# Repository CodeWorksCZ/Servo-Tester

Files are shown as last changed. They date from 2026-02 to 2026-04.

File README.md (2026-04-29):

# Servo Tester

> **Work In Progress (WIP):** This project is under active development.  
> Features, wiring, and behavior may change between commits.

RC servo tester for Arduino Pro Mini (ATmega328P, 16 MHz) with OLED UI, settings in EEPROM, and 3-channel current monitoring via INA3221.

User manual: `MANUAL.md`

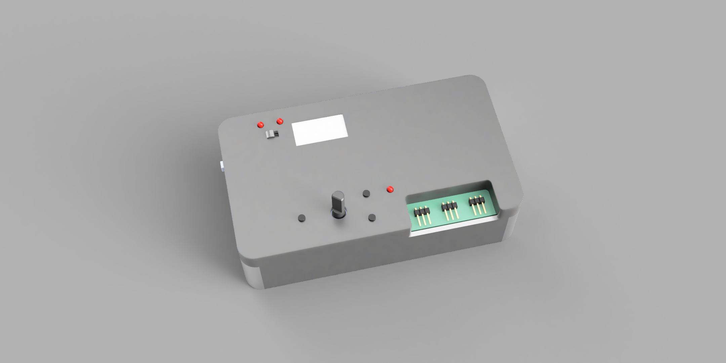
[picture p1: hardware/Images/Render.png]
Servo Tester Render


## Features

- Servo control modes: `POT`, `CENTER`, `SWEEP`
- OLED screens: `STATUS`, `GAUGE`, `CURRENT`, `VBUS`, `PEAK`
- SWEEP cycle counter shown only in SWEEP mode
- Settings menu with EEPROM persistence
- INA3221 current measurement on 3 channels
- INA3221 bus voltage and droop (`dV`) view per channel
- INA3221 per-channel warning/critical current alerts (`WR`/`CR`)
- Optional alert LED output when any channel is in `WR` or `CR`
- Optional STD/HV mode indicator LEDs
- LED startup self-test
- Automatic unit display (`mA` / `A`) on current screens
- Servo rail mode detection (`STD` / `HV`) from ADC voltage sensing on `A1`
- Compile-time UI language selection through `include/config.h` and `include/lang.h`
- Minimal serial debug line for INA3221 communication check at boot

## Controls

- `SELECT` short press: switch LCD screen (`STATUS -> GAUGE -> CURRENT -> VBUS -> PEAK`)
- `SELECT` long press: enter settings menu
- `UP` / `DOWN` in status mode: change control mode (`POT`, `CENTER`, `SWEEP`)
- `UP` / `DOWN` in menu: navigate items or change value
- `SELECT` in menu: confirm

## Settings Menu

- `Min pulse` (us)
- `Max pulse` (us)
- `Reverse`
- `Sweep cycle` (0.5-10.0 s, default 3.0 s)
- `Burn cycles` (`0` = infinite SWEEP, otherwise stop after selected cycle count)
- `Save & exit`
- `Cancel`

## Pin Mapping (Default)

| Arduino Pin | Config Name | Function |
| --- | --- | --- |
| `D2` | `BTN_UP_PIN` | UP button |
| `D3` | `BTN_DOWN_PIN` | DOWN button |
| `D4` | `ALERT_LED_PIN` | Optional INA3221 warning/critical alert LED |
| `D5` | `BTN_SELECT_PIN` | SELECT button |
| `D6` | `SERVO_PIN` | Servo signal output |
| `D7` | `STD_MODE_LED_PIN` | STD servo rail indicator LED |
| `D8` | `HV_MODE_LED_PIN` | HV servo rail indicator LED |
| `D9` | `OLED_CLK` | OLED clock (`CLK` / `D0`) |
| `D10` | `OLED_MOSI` | OLED data (`MOSI` / `DIN` / `D1`) |
| `D11` | `OLED_RESET` | OLED reset |
| `D12` | `OLED_DC` | OLED data/command |
| `D13` | `OLED_CS` | OLED chip select |
| `A0` | `POT_PIN` | Servo control potentiometer |
| `A1` | `SERVO_VSENSE_PIN` | Servo rail voltage sensing through divider |
| `A4` | I2C `SDA` | INA3221 data |
| `A5` | I2C `SCL` | INA3221 clock |

Full mapping is in `pins.txt`.

## Configuration

Main configuration is in `include/config.h`.

You can adjust:

- UI language (`SERVO_TESTER_LANGUAGE`)
- pin assignments
- button debounce and long-press timing
- servo pulse limits and step size
- sweep timing and limits
- burn-in cycle count limits
- INA3221 shunt values and calibration factors
- ADC divider and HV threshold
- LED polarity and optional LED outputs

### UI Language

The UI language is selected at compile time to keep flash usage low:

```cpp
#define SERVO_TESTER_LANGUAGE SERVO_TESTER_LANG_EN
```

Available options:

- `SERVO_TESTER_LANG_EN`
- `SERVO_TESTER_LANG_CZ`

Text resources are stored in `include/lang.h`. Only the selected language is compiled into the firmware.

### Serial Debug

When `SERIAL_DEBUG_ENABLED` is enabled, the firmware prints one INA3221 status line after boot at `115200 baud`:

- `INA3221 OK`
- `INA3221 NOT FOUND`

This is intended only as a simple wiring/communication check.

## Build

PlatformIO environment:

- file: `platformio.ini`
- env: `pro16MHzatmega328`

Libraries used:

- Adafruit SSD1306
- Adafruit GFX Library
- Adafruit INA3221 Library
- Servo

## Project Layout

- `src/main.cpp`: entry point (`setup` / `loop`)
- `src/app_controller.*`: app state machine and high-level control flow
- `src/display_ui.*`: OLED rendering
- `src/ina_monitor.*`: INA3221 handling and peak tracking
- `src/button_input.*`: button debounce and short/long press events
- `src/settings_store.*`: EEPROM load/save/validation
- `src/app_types.h`: shared app structs/enums
- `hardware/Kicad/Servo Tester/`: KiCad project files for PCB/schematic
- `hardware/Schematics/`: exported schematic PDFs
- `hardware/Datasheets/`: component datasheets
- `hardware/enclosure/`: 3D printed enclosure files and notes

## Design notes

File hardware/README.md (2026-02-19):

# Hardware Notes (WIP)

This folder contains schematics/PCB files for the Servo Tester hardware.

## Pre-Layout Checklist

- Keep logic rail (`VCC` for Pro Mini + OLED + INA3221) separate from servo power rail.
- Do not feed logic directly from HV servo rail.
- Use a common GND, but route high-current servo return separately and join at one star point.

## Servo Power Protection

- Add bulk capacitor on servo rail input: `470-1000 uF` (low-ESR, voltage rating for your rail).
- Add local decoupling near each servo connector: `100 nF` from `+BATT` to `GND`.
- Add TVS diode across servo rail (`+BATT` to `GND`) near power entry.
- Add PTC fuse in series with servo rail input.

## INA3221 Current Measurement

- Place shunts in series with servo `+` path only.
- Route INA sense lines as Kelvin connections directly to shunt pads.
- For channels that may stay unconnected, add `100k` between `INx+` and `INx-` to reduce floating behavior.
- For `R100` shunts (`0.1 ohm`), keep alert thresholds below ~`1.64 A`.

## Servo Signal Robustness

- Add series resistor on each servo signal line: `220-470 ohm` (`330 ohm` recommended).
- Keep signal and GND return close together in routing/connectors.

## Connector Safety

- Prefer keyed/polarized connectors where possible.
- If using standard 3-pin servo headers, clearly mark `SIG`, `+`, `-` on silkscreen.

## Firmware-Coupled Pins (Current Config)

- `D6`: Servo PWM output
- `D4`: Alert LED output
- `A4/A5`: INA3221 I2C
- `A0`: Potentiometer input
- `A1`: Servo rail voltage sense

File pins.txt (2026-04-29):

Arduino Pro Mini (ATmega328P) - Pin Mapping
Project: Servo Tester

Connected pins (current config)
- D2: Button UP - OK
- D3: Button DOWN - OK
- D4: Alert LED - OK
- D5: Button SELECT 0 -OK
- D6: Servo signal (PWM) - OK
- D7: STD mode LED - OK
- D8: HV mode LED - OK
- D9: OLED CLK (software SPI)
- D10: OLED MOSI (software SPI)
- D11: OLED RESET
- D12: OLED DC
- D13: OLED CS
- A0: Potentiometer input - OK
- A1: Servo rail voltage sensing (ADC divider) - OK
- A4: I2C SDA (INA3221) - OK
- A5: I2C SCL (INA3221) - OK

Digital pins
- D0 (RX): UART RX (USB-Serial programming/debug), not assigned to project I/O.
- D1 (TX): UART TX (USB-Serial programming/debug), not assigned to project I/O.
- D2: BTN_UP_PIN (button UP, active low with internal pull-up).
- D3: BTN_DOWN_PIN (button DOWN, active low with internal pull-up).
- D4: ALERT_LED_PIN (optional warning/critical LED, active level configurable in config).
- D5: BTN_SELECT_PIN (button SELECT, short press = next screen, long press = settings).
- D6: SERVO_PIN (servo signal output, PWM/timer driven by Servo library).
- D7: STD_MODE_LED_PIN (STD servo rail indicator).
- D8: HV_MODE_LED_PIN (HV servo rail indicator).
- D9: OLED_CLK (SSD1306 software SPI, display CLK/D0).
- D10: OLED_MOSI (SSD1306 software SPI, display DIN/D1).
- D11: OLED_RESET (SSD1306 reset).
- D12: OLED_DC (SSD1306 D/C).
- D13: OLED_CS (SSD1306 chip select).

Analog pins
- A0: POT_PIN (servo control potentiometer input).
- A1: SERVO_VSENSE_PIN (servo rail voltage sensing through resistor divider).
- A2: Free.
- A3: Free.
- A4: I2C SDA (INA3221 SDA).
- A5: I2C SCL (INA3221 SCL).
- A6: Free (analog input only, no digital I/O).
- A7: Free (analog input only, no digital I/O).

Power / control pins (board-level)
- RAW: External input to onboard regulator (if used by board wiring).
- VCC: 5V logic rail.
- GND: Common ground (must be shared by Arduino, INA3221, display, and servo power return).
- RST: Reset input.

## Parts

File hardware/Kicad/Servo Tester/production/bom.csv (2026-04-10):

Designator | Footprint | Quantity | Value | LCSC Part #
A1 | Clone_Pro_Mini_Socket_No_PROG | 1 | Clone_Pro_Mini_Socket
BATT1, GND1, RAIL-V1, SCL1, SDA1, SERVO-SIG1 | TestPoint_Pad_D2.0mm | 6 | TestPoint
BT1 | BAT_BK-18650-PC4 | 1 | BK-18650-PC4
C1, C2, C3, C4, C5, C6, C7, C8 | 0805 | 8 | C
D1, D2, D3 | LED_D3.0mm | 3 | LED
F1 | Fuse_LittleFuseRUEF300 | 1 | Polyfuse 3A
J1, J2, J3 | PinHeader_1x03_P2.54mm_Horizontal | 3 | Conn_01x03_Pin
J4 | AMASS_XT60PW-M_1x02_P7.20mm_Horizontal | 1 | XT60PW-M
OLED1 | OLED_0.96_SPI_Module_1x07_P2.54mm | 1 | ~
R1, R10, R11, R12, R13, R14, R15, R2, R3, R4, R5, R6, R7, R8, R9 | 0805 | 15 | R
R16, R17, R18 | 1210 | 3 | R
RV1 | Potentiometer_Bourns_PTV09A-1_Single_Vertical | 1 | 10K
SW1 | SS12D11 | 1 | SS-12DXX
SW2 | SS12D10 | 1 | SS-12DXX
SW3, SW4, SW5 | SW_PUSH_6mm_H8.5mm | 3 | SW_Push - Down
U1 | Ultra Mini-360 | 1 | Mini360
U2 | INA3221_VQFN-16_4x4mm_P0.65mm_EP2.6x2.6mm | 1 | INA3221

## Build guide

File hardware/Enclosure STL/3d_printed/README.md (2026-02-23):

# 3D Printed Enclosure

Put 3D-print enclosure files here.

Recommended structure:
- `stl/` for printable meshes
- `step/` for editable CAD exchange files
- `sources/` for native CAD project files (Fusion 360, FreeCAD, etc.)

Use clear file names with revision suffixes, for example:
- `servo_tester_case_top_revA.stl`
- `servo_tester_case_bottom_revA.stl`

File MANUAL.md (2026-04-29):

# Servo Tester - User Manual

## 1. Device Purpose

This project is an RC servo tester based on Arduino Pro Mini with:

- servo control modes (`POT`, `CENTER`, `SWEEP`)
- OLED user interface
- current and voltage monitoring through INA3221 on up to 3 channels
- STD/HV servo rail indication
- optional warning/critical alert LED

## 2. Basic Wiring

Use `pins.txt` as the current source of truth for pin mapping.

Minimum required for operation:

- Arduino Pro Mini with uploaded firmware
- OLED display (software SPI)
- `SELECT` button, ideally also `UP` and `DOWN`
- servo signal on `D6`
- common `GND` between Arduino and servo power

Optional INA3221 connection:

- `A4` = `SDA`
- `A5` = `SCL`

Optional LED outputs:

- `D4` = INA3221 warning/critical alert LED
- `D7` = STD servo rail indicator LED
- `D8` = HV servo rail indicator LED

## 3. Power

- logic side (Arduino + OLED + INA3221): stable `5V`
- servo side: according to servo type (`STD` or `HV`)
- always use a common ground between logic and servo power

Recommended on the servo rail:

- bulk capacitor `470-1000 uF`
- local `100 nF` capacitor near each servo connector

## 4. Build and Upload

From the project root:

```powershell
& "$env:USERPROFILE\.platformio\penv\Scripts\platformio.exe" run
& "$env:USERPROFILE\.platformio\penv\Scripts\platformio.exe" run -t upload
```

## 5. Controls

In status mode:

- short press `SELECT`: next screen
- long press `SELECT`: enter settings
- `UP` / `DOWN`: change control mode (`POT` / `CENTER` / `SWEEP`)

In settings:

- `UP` / `DOWN`: move in the menu or change the current value
- `SELECT`: confirm / enter edit mode / leave edit mode

## 6. Control Modes

- `POT`: servo position follows the potentiometer
- `CENTER`: fixed center position
- `SWEEP`: automatic cycle between minimum and maximum pulse

In `SWEEP`, the status screen shows a cycle counter:

- infinite mode: completed cycle count
- burn-in mode: remaining cycles

## 7. OLED Screens

- `STATUS`: pulse, angle, range, reverse, SWP counter
- `GAUGE`: 0-100% needle gauge
- `CURRENT`: channel currents and `WR/CR` flags
- `VBUS`: bus voltage and voltage droop (`dV`) on each channel
- `PEAK`: maximum current on each channel

Short press `SELECT` to cycle through the screens:

```text
STATUS -> GAUGE -> CURRENT -> VBUS -> PEAK -> STATUS
```

### 7.1 STATUS Screen

Shows the active servo output and the selected control mode.

```text
STATUS                    M:POT
PWR:STD
-------------------------------
Pulse:1500us
Angle:90deg
Range:1000-2000
Rev:OFF            U/D:Mode
```

Fields:

- `M`: active control mode (`POT`, `CEN`, `SWP`)
- `PWR`: detected servo rail mode (`STD` or `HV`)
- `Pulse`: current servo pulse width in microseconds
- `Angle`: approximate 0-180 degree value calculated from the configured pulse range
- `Range`: configured minimum and maximum pulse
- `Rev`: reverse mode state

In `SWP` mode, the bottom-right area changes:

```text
Rev:OFF            Cnt:12
```

If `Burn cycles` is greater than `0`, it shows remaining cycles instead:

```text
Rev:OFF            L:900
```

### 7.2 GAUGE Screen

Shows servo position as a 0-100% gauge.

```text
GAUGE                     M:POT
PWR:STD
-------------------------------

        .---------.
   0   /           \   100
            \|
             o      50%
```

The gauge uses the configured servo pulse range:

- `0%` = configured minimum pulse
- `100%` = configured maximum pulse
- the needle is display-filtered to reduce small visible jitter from potentiometer noise

### 7.3 CURRENT Screen

Shows live current from the INA3221 channels.

```text
CURRENT                   M:POT
PWR:STD
-------------------------------
CH1: 125.4 mA          --
CH2: 0.0 mA            --
CH3: 1.25 A            WR
S:Next H:Menu
```

Fields:

- `CH1-CH3`: current per INA3221 channel
- `--`: no alert
- `WR`: warning threshold exceeded
- `CR`: critical threshold exceeded

The unit switches automatically:

- below `1000 mA`: shown as `mA`
- from `1000 mA`: shown as `A`

### 7.4 VBUS Screen

Shows bus voltage and voltage droop for each INA3221 channel.

```text
VBUS                      M:POT
PWR:STD
-------------------------------
1:6.05V d0.03          --
2:6.04V d0.04          --
3:5.91V d0.17          WR
S:Next H:Menu
```

Fields:

- left value: measured bus voltage on the channel
- `d`: voltage droop from the highest observed bus voltage since startup/reset
- alert token: `--`, `WR`, or `CR`

This screen is useful for checking voltage sag when a servo is loaded.

### 7.5 PEAK Screen

Shows maximum measured current per channel.

```text
PEAK                      M:POT
PWR:STD
-------------------------------
CH1 max:420.0 mA
CH2 max:0.0 mA
CH3 max:1.80 A
S:Next H:Menu
```

Peak values are tracked while the device is running. They are useful for checking short servo current spikes during movement or stall testing.

## 8. Settings

- `Min pulse`
- `Max pulse`
- `Reverse`
- `Sweep cycle` (`0.5-10.0 s`, default `3.0 s`)
- `Burn cycles` (`0` = infinite SWEEP, otherwise stop after selected cycle count)
- `Save & exit`
- `Cancel`

Settings are stored in EEPROM.

## 9. Alerts (`WR` / `CR`)

- `WR` = warning threshold
- `CR` = critical threshold

Threshold values are configured in `include/config.h`.

When any enabled INA3221 channel enters `WR` or `CR`, the optional alert LED on `D4` turns on.

## 10. STD/HV Indication

The firmware reads the servo rail voltage on `A1` through a resistor divider.

- below the configured threshold: `STD`
- above the configured threshold: `HV`

The active mode is shown on the OLED and can also be indicated by LEDs:

- `D7`: STD mode LED
- `D8`: HV mode LED

## 11. Language Selection

The OLED language is selected at compile time in `include/config.h`:

```cpp
#define SERVO_TESTER_LANGUAGE SERVO_TESTER_LANG_EN
```

Available options:

- `SERVO_TESTER_LANG_EN`
- `SERVO_TESTER_LANG_CZ`

Text resources are stored in `include/lang.h`.

## 12. Serial INA3221 Check

If `SERIAL_DEBUG_ENABLED` is enabled in `include/config.h`, the device prints one INA3221 status line after boot at `115200 baud`:

- `INA3221 OK`
- `INA3221 NOT FOUND`

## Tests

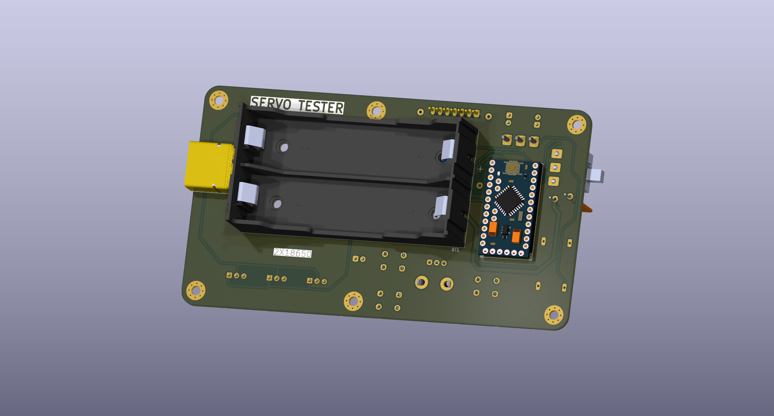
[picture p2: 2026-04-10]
hardware/Images/Servo Tester PCB3.png

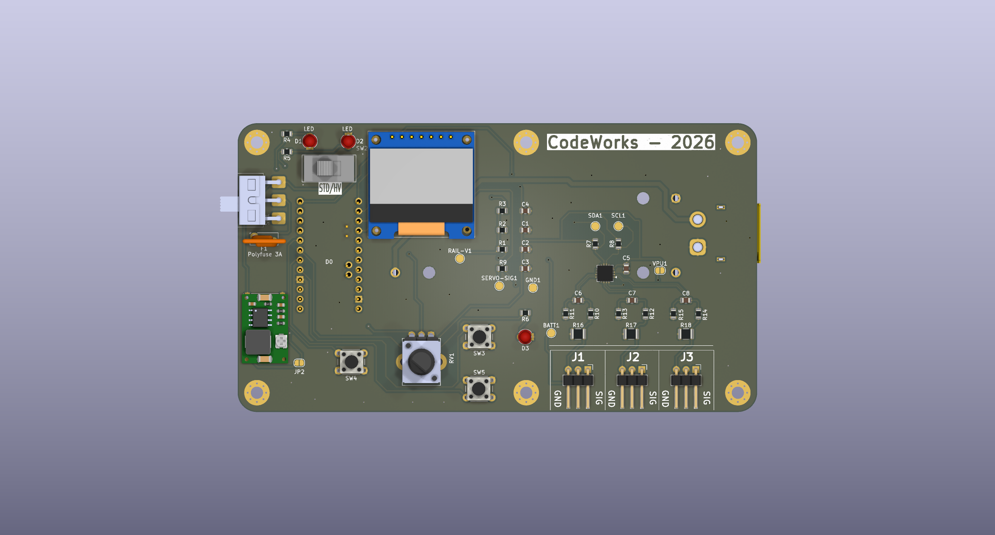
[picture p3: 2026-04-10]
hardware/Images/Servo Tester PCB1.png

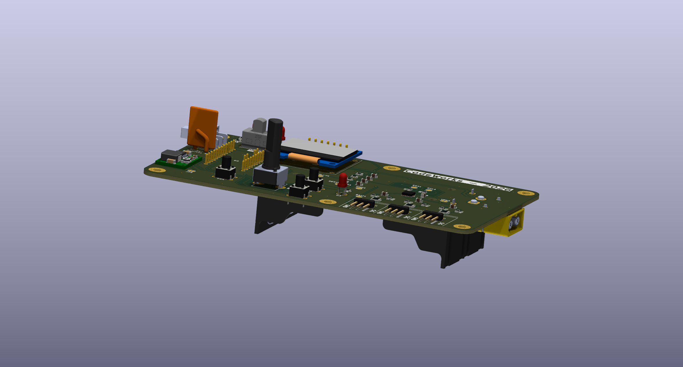
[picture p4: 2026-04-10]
hardware/Images/Servo Tester PCB2.png

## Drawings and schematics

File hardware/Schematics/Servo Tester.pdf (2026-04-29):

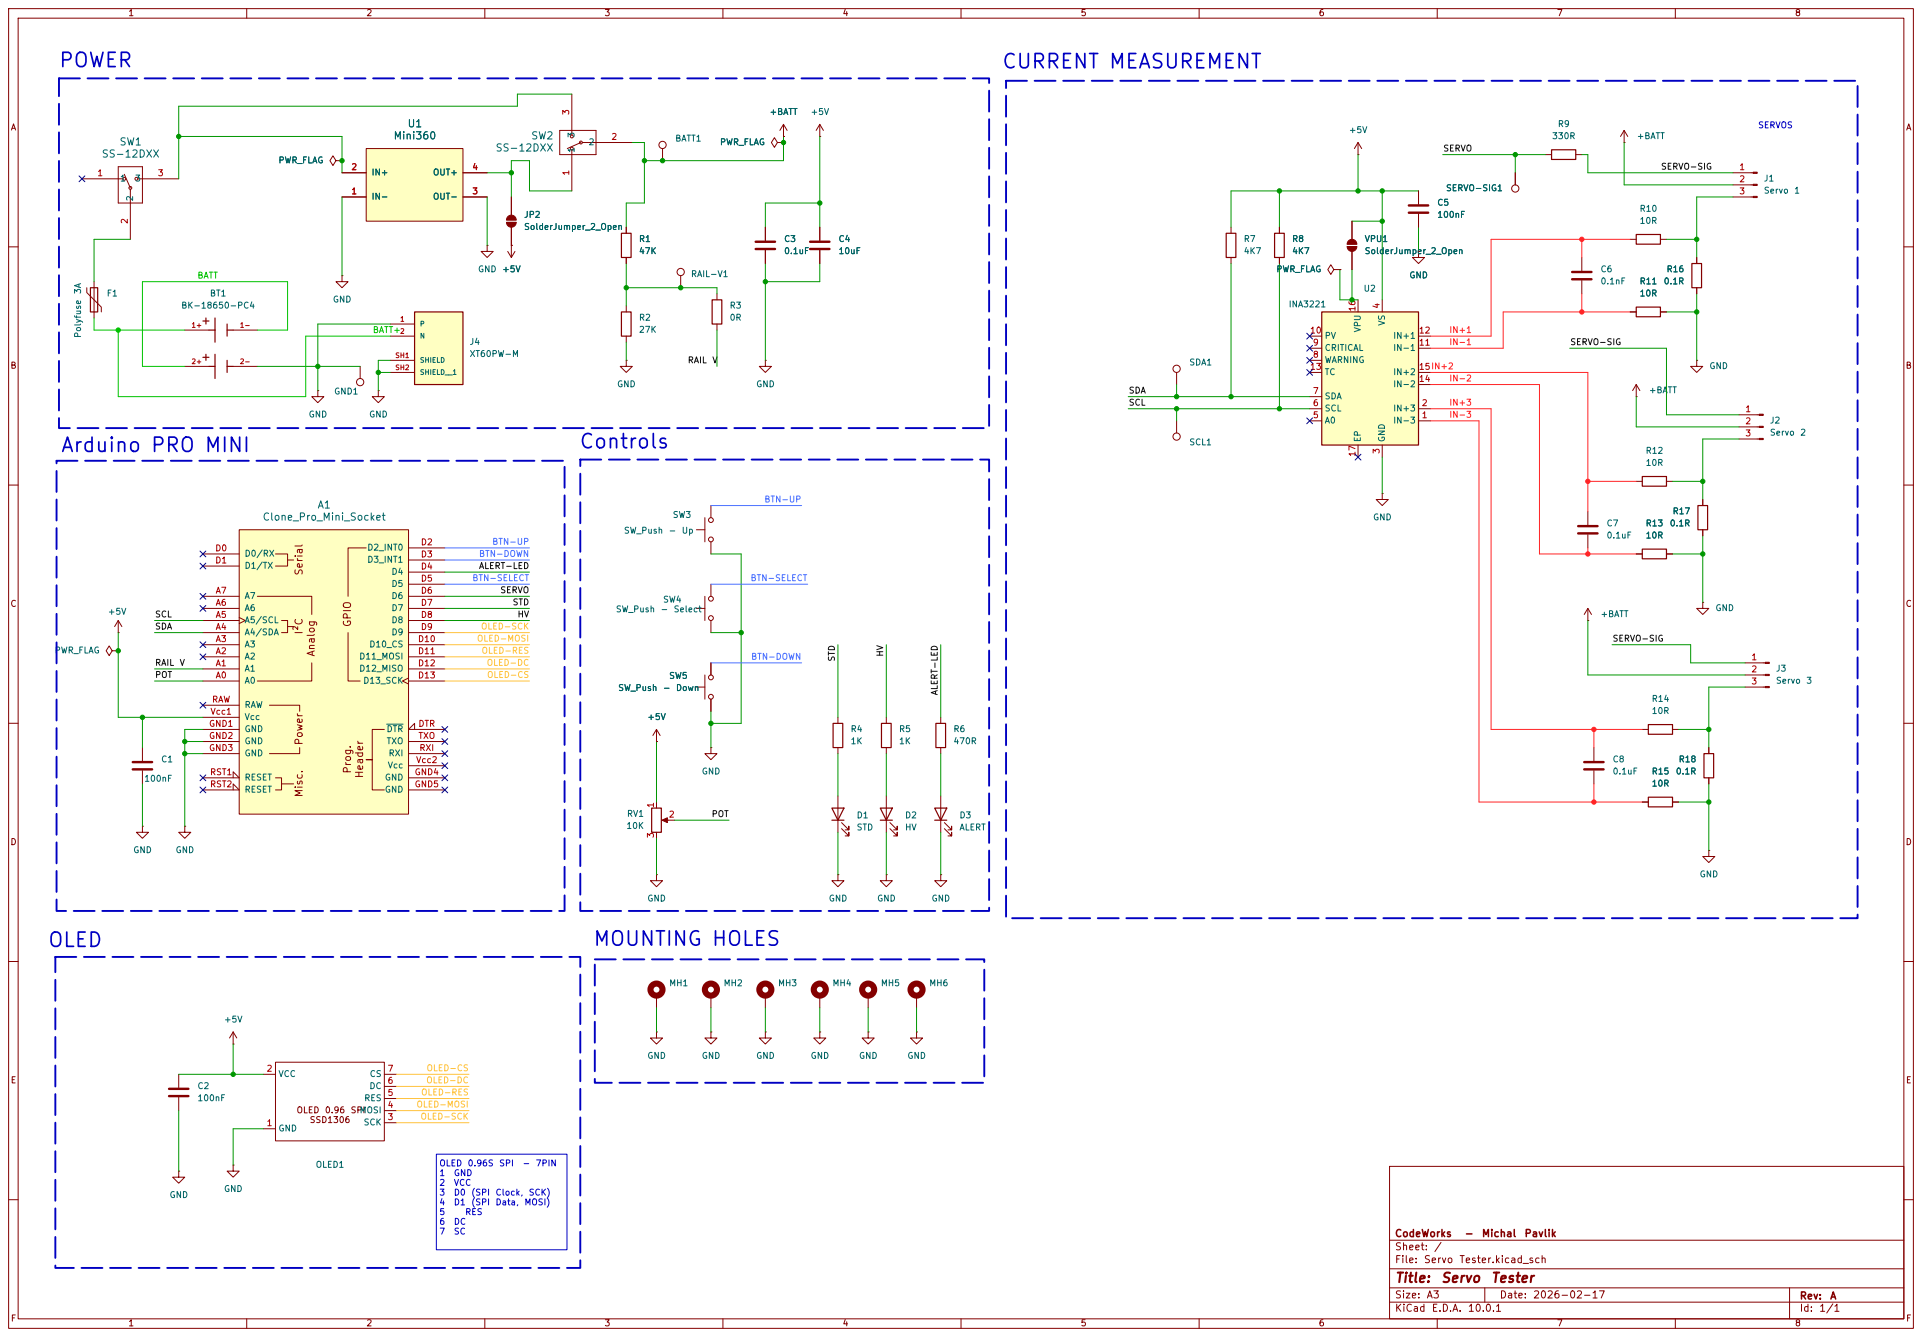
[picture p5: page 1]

IN-2 14 IN+2 15 VPU 16 EP 17 U2

GND
BTN-SELECT OLED-SCK OLED-RES OLED-MOSI

Size: A3 | Rev: A | F Date: 2026-02-17
KiCad E.D.A. 10.0.1 | Id: 1/1

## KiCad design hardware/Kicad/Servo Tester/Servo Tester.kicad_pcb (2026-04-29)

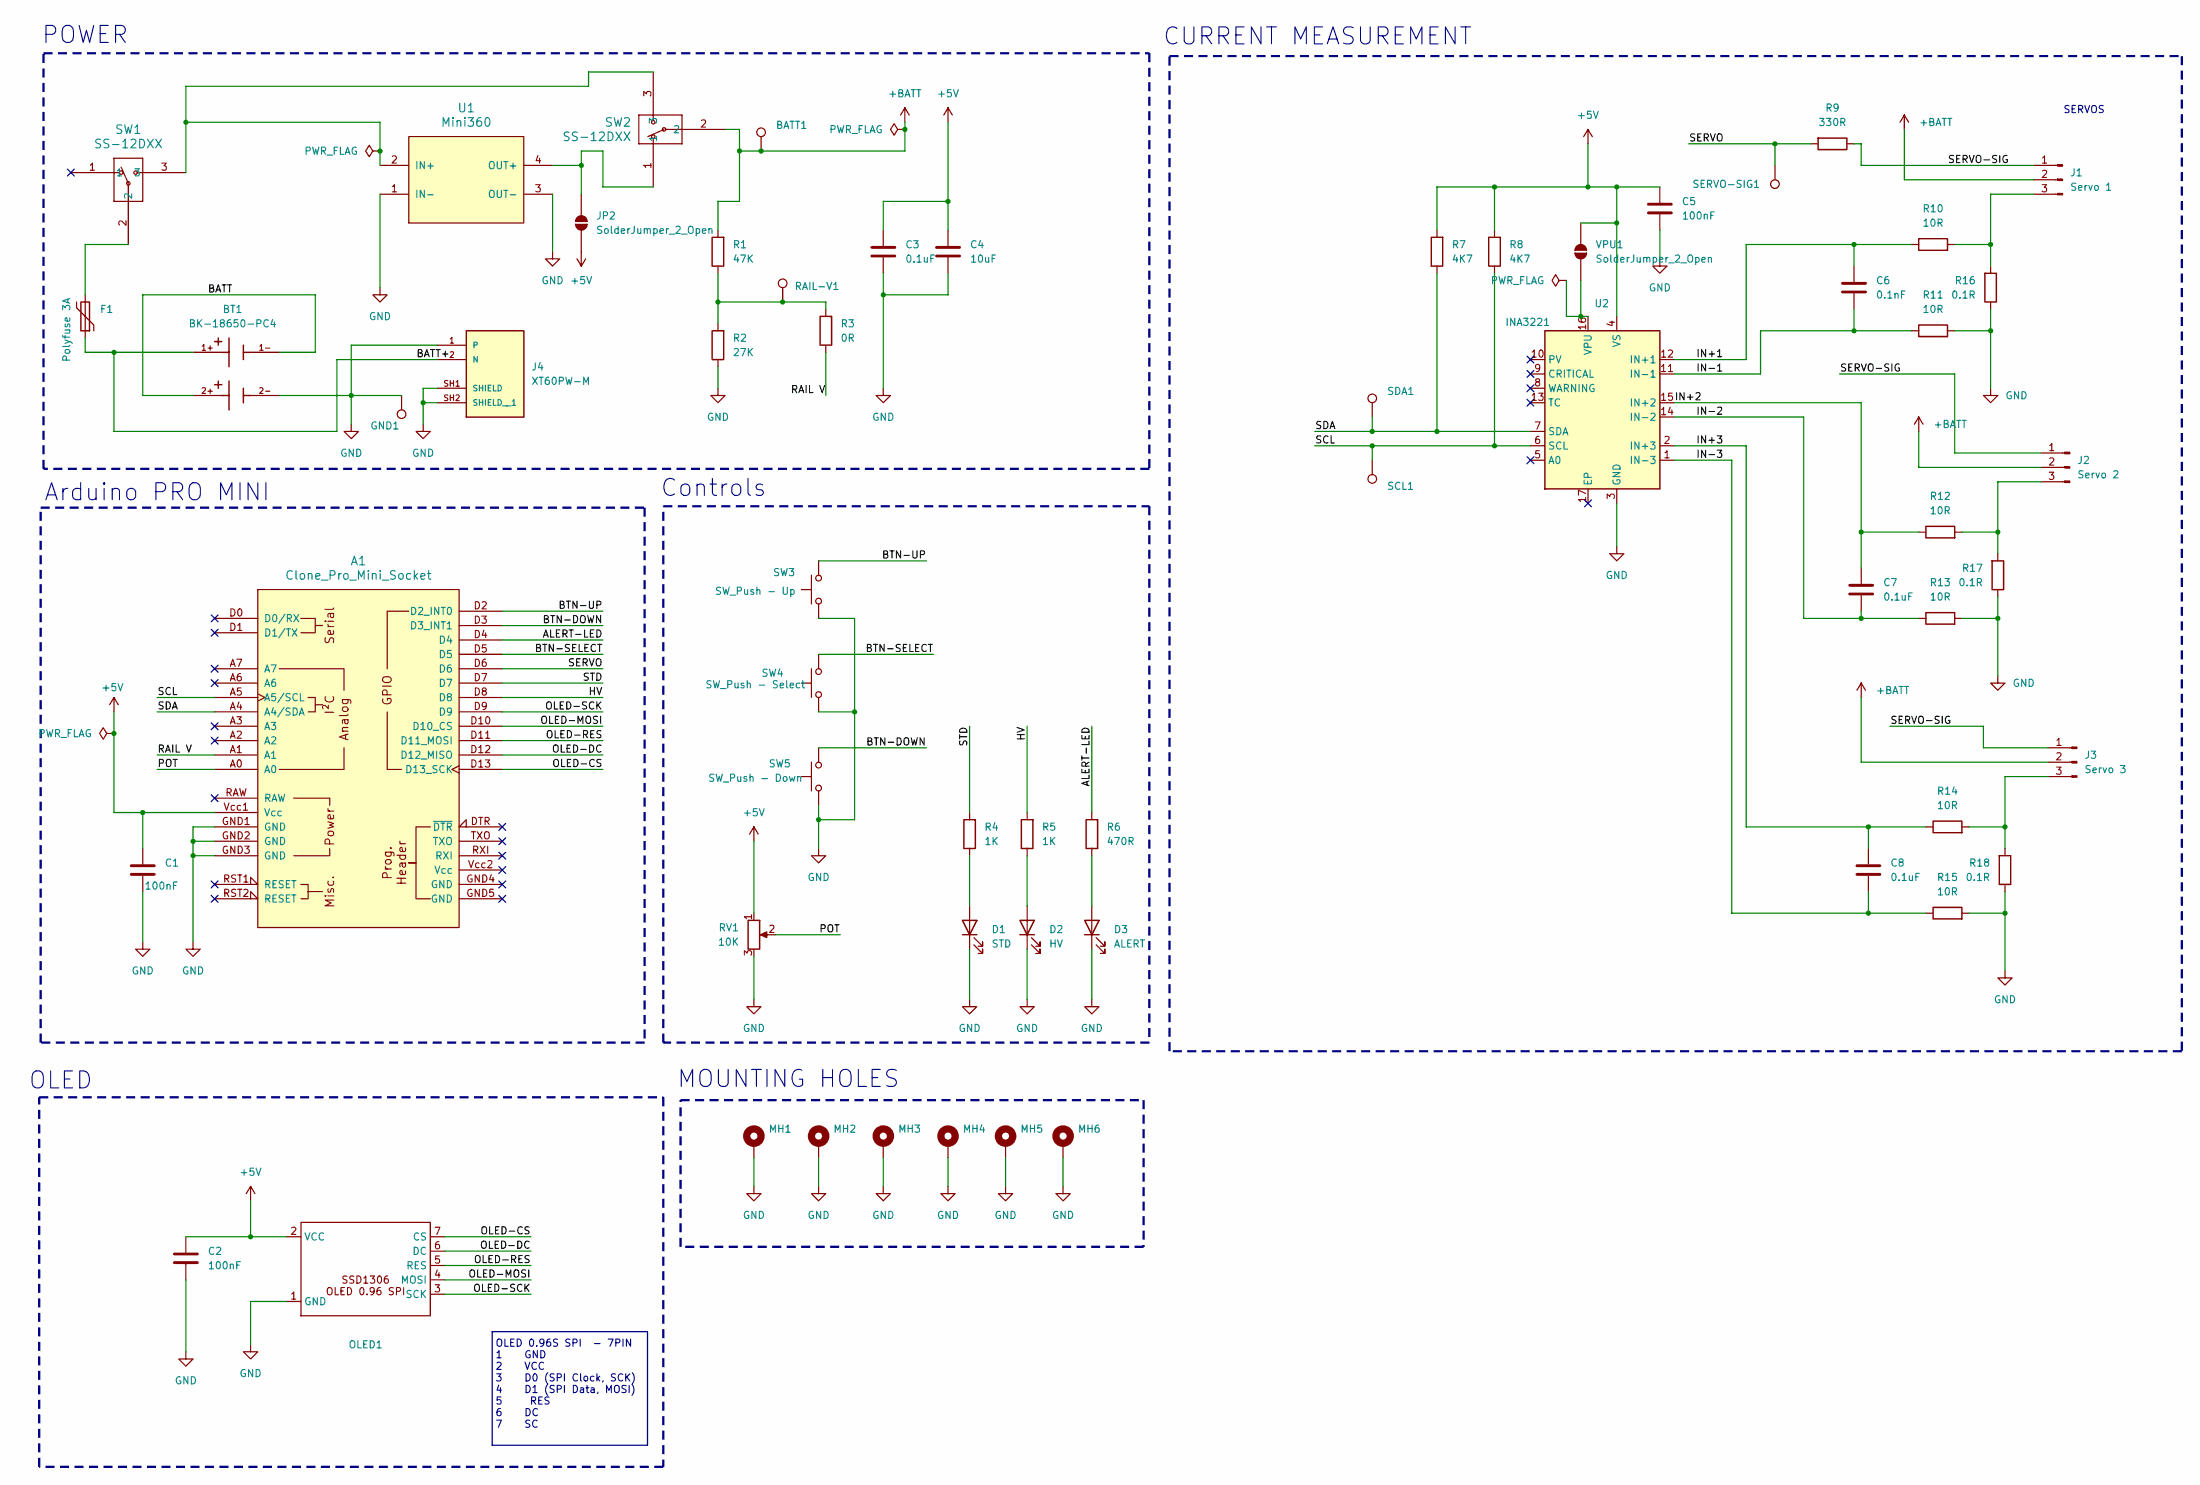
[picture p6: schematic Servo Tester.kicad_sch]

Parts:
A1: Clone_Pro_Mini_Socket; Clone_Pro_Mini_Socket_No_PROG
BATT1: TestPoint; TestPoint_Pad_D2.0mm
BT1: BK-18650-PC4; BAT_BK-18650-PC4; PARTREV K
C1, C2, C5: 100nF; C_0805_2012Metric
C3, C7, C8: 0.1uF; C_0805_2012Metric
C4: 10uF; C_0805_2012Metric
C6: 0.1nF; C_0805_2012Metric
D1: STD; LED_D3.0mm
D2: HV; LED_D3.0mm
D3: ALERT; LED_D3.0mm
F1: Polyfuse 3A; Fuse_LittleFuseRUEF300
GND1: TestPoint; TestPoint_Pad_D2.0mm
J1: Servo 1; PinHeader_1x03_P2.54mm_Horizontal
J2: Servo 2; PinHeader_1x03_P2.54mm_Horizontal
J3: Servo 3; PinHeader_1x03_P2.54mm_Horizontal
J4: XT60PW-M; AMASS_XT60PW-M_1x02_P7.20mm_Horizontal; PARTREV 1.2
JP2: SolderJumper_2_Open; SolderJumper-2_P1.3mm_Open_RoundedPad1.0x1.5mm
MH1, MH2, MH3, MH4, MH5, MH6: MountingHole_3.2mm_M3_Pad_Via
OLED1: OLED_0.96_SPI_Module_1x07_P2.54mm
R1: 47K; R_0805_2012Metric
R2: 27K; R_0805_2012Metric
R3: 0R; R_0805_2012Metric
R4, R5: 1K; R_0805_2012Metric
R6: 470R; R_0805_2012Metric
R7, R8: 4K7; R_0805_2012Metric
R9: 330R; R_0805_2012Metric
R10, R11, R12, R13, R14, R15: 10R; R_0805_2012Metric
R16, R17, R18: 0.1R; R_1210_3225Metric
RAIL-V1: TestPoint; TestPoint_Pad_D2.0mm
RV1: 10K; Potentiometer_Bourns_PTV09A-1_Single_Vertical
SCL1: TestPoint; TestPoint_Pad_D2.0mm
SDA1: TestPoint; TestPoint_Pad_D2.0mm
SERVO-SIG1: TestPoint; TestPoint_Pad_D2.0mm
SW1: SS-12DXX; SS12D11
SW2: SS-12DXX; SS12D10
SW3: SW_Push - Up; SW_PUSH_6mm_H8.5mm
SW4: SW_Push - Select; SW_PUSH_6mm_H8.5mm
SW5: SW_Push - Down; SW_PUSH_6mm_H8.5mm
U1: Mini360; Ultra Mini-360
U2: INA3221; INA3221_VQFN-16_4x4mm_P0.65mm_EP2.6x2.6mm
VPU1: SolderJumper_2_Open; SolderJumper-2_P1.3mm_Open_RoundedPad1.0x1.5mm

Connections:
+5V: A1.Vcc1 (Vcc), C1.1, C2.1, C3.1, C4.1, C5.1, JP2.1 (A), OLED1.2 (VCC), R7.2, R8.2, RV1.1, U2.4 (VS), VPU1.2 (B)
+BATT: BATT1.1 (1_1), J1.2, J2.2, J3.2, R1.2, SW2.2
/ALERT-LED: A1.D4, R6.2
/BATT: BT1.1-, BT1.2+
/BATT+: BT1.1+, F1.1, J4.2 (N)
/BTN-DOWN: A1.D3 (D3_INT1), SW5.2
/BTN-SELECT: A1.D5, SW4.2
/BTN-UP: A1.D2 (D2_INT0), SW3.2
/HV: A1.D8, R5.2
/IN+1: C6.1, R10.1, U2.12 (IN+1)
/IN+2: C7.1, R12.1, U2.15 (IN+2)
/IN+3: C8.1, R14.1, U2.2 (IN+3)
/IN-1: C6.2, R11.1, U2.11 (IN-1)
/IN-2: C7.2, R13.1, U2.14 (IN-2)
/IN-3: C8.2, R15.1, U2.1 (IN-3)
/OLED-CS: A1.D13 (D13_SCK), OLED1.7 (CS)
/OLED-DC: A1.D12 (D12_MISO), OLED1.6 (DC)
/OLED-MOSI: A1.D10 (D10_CS), OLED1.4 (MOSI)
/OLED-RES: A1.D11 (D11_MOSI), OLED1.5 (RES)
/OLED-SCK: A1.D9, OLED1.3 (SCK)
/POT: A1.A0, RV1.2
/RAIL V: A1.A1, R3.1
/SCL: A1.A5 (A5/SCL), R8.1, SCL1.1 (1_1), U2.6 (SCL)
/SDA: A1.A4 (A4/SDA), R7.1, SDA1.1 (1_1), U2.7 (SDA)
/SERVO: A1.D6, R9.2, SERVO-SIG1.1 (1_1)
/SERVO-SIG: J1.1, J2.1, J3.1, R9.1
/STD: A1.D7, R4.2
GND: A1.GND1 (GND), A1.GND2 (GND), A1.GND3 (GND), BT1.2-, C1.2, C2.2, C3.2, C4.2, C5.2, D1.1 (K), D2.1 (K), D3.1 (K), GND1.1 (1_1), J4.1, J4.SH1 (SHIELD), J4.SH2 (SHIELD__1), MH1.1 (1_1), MH2.1 (1_1), MH3.1 (1_1), MH4.1 (1_1), MH5.1 (1_1), MH6.1 (1_1), OLED1.1 (GND), R2.1, R11.2, R13.2, R15.2, R16.1, R17.1, R18.1, RV1.3, SW3.1, SW4.1, SW5.1, U1.1 (IN-), U1.3 (OUT-), U2.3 (GND)
unnamed: D1.2 (A), R4.1
unnamed: D2.2 (A), R5.1
unnamed: D3.2 (A), R6.1
unnamed: F1.2, SW1.2
unnamed: J1.3, R10.2, R16.2
unnamed: J2.3, R12.2, R17.2
unnamed: J3.3, R14.2, R18.2
unnamed: JP2.2 (B), SW2.1, U1.4 (OUT+)
unnamed: R1.1, R2.2, R3.2, RAIL-V1.1 (1_1)
unnamed: SW1.3, SW2.3, U1.2 (IN+)
unnamed: U2.16 (VPU), VPU1.1 (A)

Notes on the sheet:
CURRENT MEASUREMENT
Controls
Arduino PRO MINI
POWER
OLED
MOUNTING HOLES
SERVOS
OLED 0.96S SPI - 7PIN 1 GND 2 VCC 3 D0 (SPI Clock, SCK) 4 D1 (SPI Data, MOSI) 5 RES 6 DC 7 SC

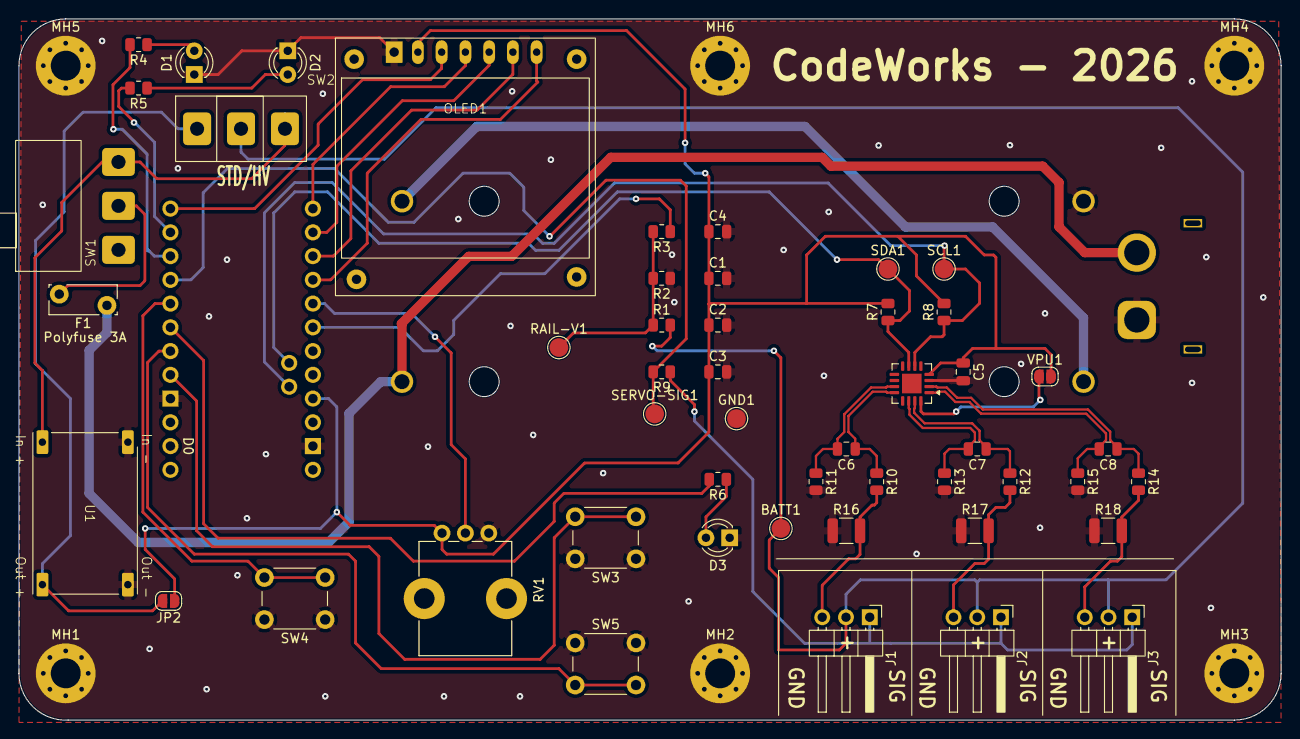
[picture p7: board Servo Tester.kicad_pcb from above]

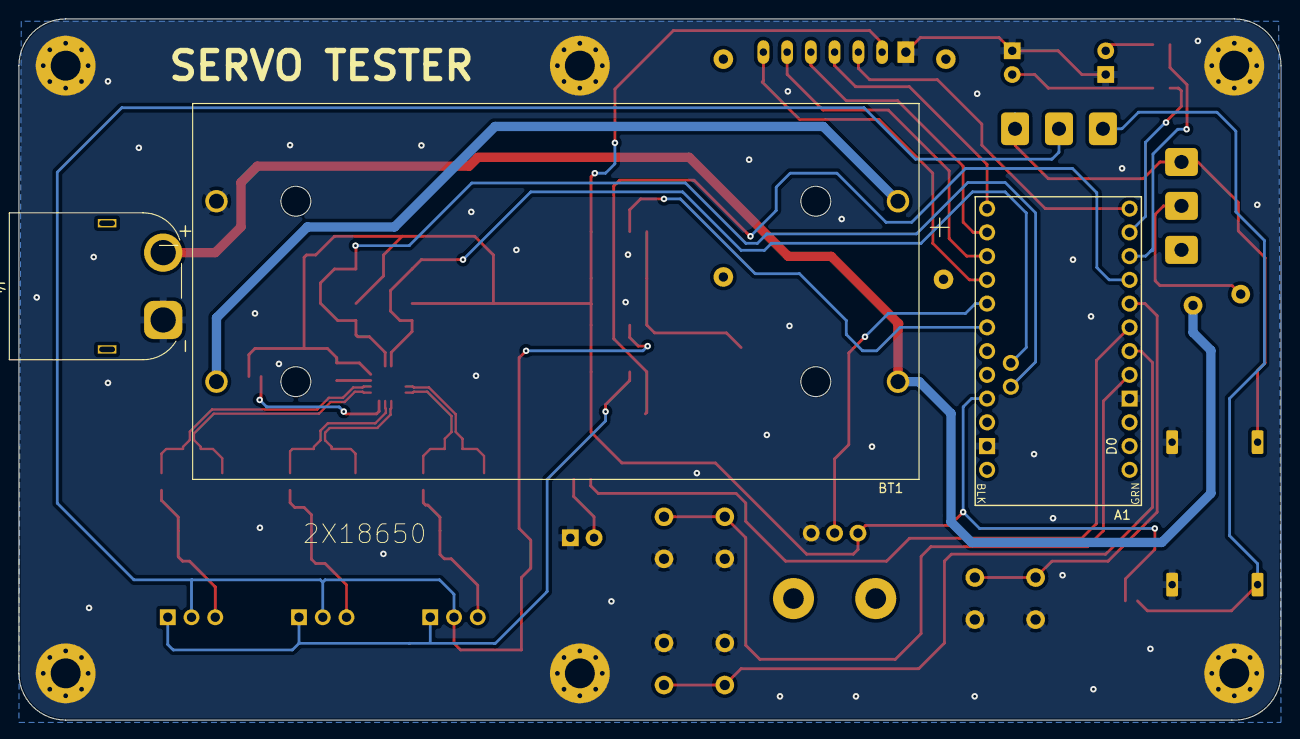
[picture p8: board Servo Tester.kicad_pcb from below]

Board: 2 copper layers, 135.0 x 75.0 mm, 59 parts (3 on the bottom side), 39 nets.

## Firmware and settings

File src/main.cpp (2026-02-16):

#include <Arduino.h>

#include "app_controller.h"

namespace
{
// Single app instance for the whole firmware runtime.
AppController app;
} // namespace

void setup()
{
  // Initialize all peripherals and application state.
  app.begin();
}

void loop()
{
  // Periodic non-blocking update of IO, state machine, and UI.
  app.update();
}

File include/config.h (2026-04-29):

#ifndef CONFIG_H
#define CONFIG_H

#include <Arduino.h>

// Compile-time UI language selection. Only the selected language is compiled in.
#define SERVO_TESTER_LANG_EN 0
#define SERVO_TESTER_LANG_CZ 1
#define SERVO_TESTER_LANGUAGE SERVO_TESTER_LANG_EN

namespace Config
{
// Centralized compile-time configuration.
// Keep hardware pinout and behavior constants here.

// SSD1306 OLED parameters (software SPI wiring)
constexpr uint8_t SCREEN_WIDTH = 128;
constexpr uint8_t SCREEN_HEIGHT = 64;
constexpr uint8_t OLED_MOSI = 10;   // Display DIN / D1
constexpr uint8_t OLED_CLK = 9;   // Display CLK / D0
constexpr uint8_t OLED_DC = 12;    // Display D/C
constexpr uint8_t OLED_CS = 13;    // Display CS
constexpr uint8_t OLED_RESET = 11; // Display RST

// Device I/O pins
constexpr uint8_t SERVO_PIN = 6;
constexpr uint8_t POT_PIN = A0;
// Servo rail voltage sensing (ADC)
constexpr uint8_t SERVO_VSENSE_PIN = A1;
constexpr float SERVO_VSENSE_R1_OHMS = 180000.0f; // top resistor to V+
constexpr float SERVO_VSENSE_R2_OHMS = 100000.0f; // bottom resistor to GND
constexpr float SERVO_VSENSE_ADC_REF_V = 5.0f;      // AVR ADC reference voltage.
constexpr float SERVO_VSENSE_HV_THRESHOLD_V = 7.2f; // Above this, UI reports HV mode.
constexpr uint8_t BTN_UP_PIN = 2;
constexpr uint8_t BTN_DOWN_PIN = 3;
constexpr uint8_t BTN_SELECT_PIN = 5;
// Optional alert LED output. Set to 255 to disable.
constexpr uint8_t ALERT_LED_PIN = 4;
constexpr bool ALERT_LED_ACTIVE_HIGH = true;
constexpr bool ALERT_LED_FORCE_ON = false;
// Optional power mode indicator LEDs. Set pin to 255 to disable.
constexpr uint8_t STD_MODE_LED_PIN = 7;
constexpr uint8_t HV_MODE_LED_PIN = 8;
constexpr bool POWER_MODE_LED_ACTIVE_HIGH = true;
constexpr bool HV_MODE_LED_FORCE_ON = false;
constexpr uint16_t LED_STARTUP_TEST_MS = 500;
// External STD/HV mode switch input (to GND or VCC).
// Set MODE_SWITCH_PIN to 255 to disable and use ADC voltage detection.
constexpr uint8_t MODE_SWITCH_PIN = 255;
constexpr bool MODE_SWITCH_ACTIVE_LOW = true;
constexpr bool MODE_SWITCH_USE_PULLUP = true;

// Serial debug output for INA3221 communication checks.
constexpr bool SERIAL_DEBUG_ENABLED = true;
constexpr uint32_t SERIAL_DEBUG_BAUD = 115200;

// UI refresh rate and button debounce
constexpr uint16_t UI_REFRESH_MS = 80;       // OLED redraw period.
constexpr uint16_t BUTTON_DEBOUNCE_MS = 35;  // Debounce filter time.
constexpr uint16_t BUTTON_LONG_PRESS_MS = 700;
constexpr uint8_t GAUGE_DEADBAND_PERCENT = 1; // Ignore tiny +/- display jitter (% of span).
constexpr uint8_t GAUGE_MAX_STEP_PERCENT = 4; // Max display step per redraw (% of span).
// true: pressed = LOW (button to GND), false: pressed = HIGH
constexpr bool BUTTON_ACTIVE_LOW = true;
// true: enable internal pull-up resistors on button pins
constexpr bool BUTTON_USE_INTERNAL_PULLUP = true;

// INA3221 current monitor configuration
constexpr uint8_t INA3221_I2C_ADDRESS = 0x40;
constexpr float INA3221_SHUNT_OHMS_CH1 = 0.1f;
constexpr float INA3221_SHUNT_OHMS_CH2 = 0.1f;
constexpr float INA3221_SHUNT_OHMS_CH3 = 0.1f;
// Software calibration multipliers (1.0 = no correction).
constexpr float INA3221_CAL_FACTOR_CH1 = 1.0f;
constexpr float INA3221_CAL_FACTOR_CH2 = 1.0f;
constexpr float INA3221_CAL_FACTOR_CH3 = 1.0f;
constexpr uint16_t INA3221_REFRESH_MS = 200; // Sensor polling interval.
// Alert thresholds in milliamps (shown as WR/CR on LCD).
// For 0.1 ohm shunts (R100), keep thresholds below ~1.64 A measurement limit.
constexpr float INA3221_WARN_MA_CH1 = 900.0f;
constexpr float INA3221_WARN_MA_CH2 = 900.0f;
constexpr float INA3221_WARN_MA_CH3 = 900.0f;
constexpr float INA3221_CRIT_MA_CH1 = 1300.0f;
constexpr float INA3221_CRIT_MA_CH2 = 1300.0f;
constexpr float INA3221_CRIT_MA_CH3 = 1300.0f;
// Ignore alert flags for channels with effectively no bus voltage (floating/unwired).
constexpr float INA3221_ALERT_MIN_BUS_V = 0.5f;

// Servo pulse limits and edit behavior
constexpr uint16_t PULSE_MIN_LIMIT = 500;
constexpr uint16_t PULSE_MAX_LIMIT = 2500;
constexpr uint16_t PULSE_DEFAULT_MIN = 1000;
constexpr uint16_t PULSE_DEFAULT_MAX = 2000;
constexpr uint16_t PULSE_STEP_US = 10;
constexpr uint16_t MIN_PULSE_SPAN_US = 100;
// Sweep mode behavior
constexpr uint16_t SWEEP_STEP_US = 5; // Delta applied every sweep step.
constexpr uint16_t SWEEP_CYCLE_MIN_MS = 500;
constexpr uint16_t SWEEP_CYCLE_MAX_MS = 10000;
constexpr uint16_t SWEEP_CYCLE_DEFAULT_MS = 3000;
constexpr uint16_t SWEEP_CYCLE_STEP_MS = 500;
constexpr uint16_t BURN_CYCLES_MIN = 0;
constexpr uint16_t BURN_CYCLES_MAX = 9999;
constexpr uint16_t BURN_CYCLES_DEFAULT = 0;
constexpr uint16_t BURN_CYCLES_STEP = 100;

// EEPROM storage layout/version
constexpr uint8_t SETTINGS_VERSION = 4;
constexpr int EEPROM_ADDR = 0; // Base EEPROM address for Settings struct.
} // namespace Config

#endif

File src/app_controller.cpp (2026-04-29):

#include "app_controller.h"

#include <Wire.h>

#include "config.h"
#include "display_ui.h"
#include "settings_store.h"

namespace
{
void debugSerialBegin()
{
  const uint16_t ubrr = static_cast<uint16_t>((F_CPU / 8UL / Config::SERIAL_DEBUG_BAUD) - 1UL);
  UCSR0A = _BV(U2X0);
  UBRR0H = static_cast<uint8_t>(ubrr >> 8);
  UBRR0L = static_cast<uint8_t>(ubrr);
  UCSR0B = _BV(TXEN0);
  UCSR0C = _BV(UCSZ01) | _BV(UCSZ00);
}

void debugSerialWrite(const char *text)
{
  while (*text != '\0')
  {
    while ((UCSR0A & _BV(UDRE0)) == 0)
    {
    }
    UDR0 = static_cast<uint8_t>(*text);
    ++text;
  }
}
} // namespace

const char *AppController::modeLabel() const
{
  // Short labels are used in the OLED header.
  if (controlMode_ == CONTROL_POT)
  {
    return "POT";
  }

  if (controlMode_ == CONTROL_CENTER)
  {
    return "CEN";
  }

  return "SWP";
}

uint8_t AppController::pulseToAngle(const uint16_t pulseUs, const Settings &settings) const
{
  // Convert pulse range to 0..180 for user-friendly display.
  if (settings.maxPulseUs <= settings.minPulseUs)
  {
    return 0;
  }

  const long angle = map(pulseUs, settings.minPulseUs, settings.maxPulseUs, 0, 180);
  if (angle < 0)
  {
    return 0;
  }

  if (angle > 180)
  {
    return 180;
  }

  return static_cast<uint8_t>(angle);
}

uint8_t AppController::pulseToPercent(const uint16_t pulseUs, const Settings &settings) const
{
  // Convert pulse range to 0..100 for gauge screen.
  if (settings.maxPulseUs <= settings.minPulseUs)
  {
    return 0;
  }

  const long percent = map(pulseUs, settings.minPulseUs, settings.maxPulseUs, 0, 100);
  if (percent < 0)
  {
    return 0;
  }

  if (percent > 100)
  {
    return 100;
  }

  return static_cast<uint8_t>(percent);
}

uint16_t AppController::stabilizeDisplayPulseUs(const uint16_t rawPulseUs, const Settings &settings)
{
  // First sample initializes the filter to current value.
  if (!displayPulseInitialized_)
  {
    displayPulseUs_ = rawPulseUs;
    displayPulseInitialized_ = true;
    return displayPulseUs_;
  }

  if (settings.maxPulseUs <= settings.minPulseUs)
  {
    displayPulseUs_ = rawPulseUs;
    return displayPulseUs_;
  }

  const int16_t spanUs = static_cast<int16_t>(settings.maxPulseUs - settings.minPulseUs);
  int16_t deadbandUs = (spanUs * static_cast<int16_t>(Config::GAUGE_DEADBAND_PERCENT)) / 100;
  int16_t maxStepUs = (spanUs * static_cast<int16_t>(Config::GAUGE_MAX_STEP_PERCENT)) / 100;
  if (deadbandUs < 1)
  {
    deadbandUs = 1;
  }
  if (maxStepUs < 1)
  {
    maxStepUs = 1;
  }

  const int16_t diff = static_cast<int16_t>(rawPulseUs) - static_cast<int16_t>(displayPulseUs_);
  if (abs(diff) <= deadbandUs)
  {
    // Ignore tiny oscillations from ADC/pot noise.
    return displayPulseUs_;
  }

  // Smooth toward target while limiting per-frame movement.
  int16_t step = diff / 3;
  if (step == 0)
  {
    step = (diff > 0) ? 1 : -1;
  }

  if (step > maxStepUs)
  {
    step = maxStepUs;
  }
  else if (step < -maxStepUs)
  {
    step = -maxStepUs;
  }

  int16_t next = static_cast<int16_t>(displayPulseUs_) + step;
  if (next < static_cast<int16_t>(settings.minPulseUs))
  {
    next = settings.minPulseUs;
  }
  else if (next > static_cast<int16_t>(settings.maxPulseUs))
  {
    next = settings.maxPulseUs;
  }

  displayPulseUs_ = static_cast<uint16_t>(next);
  return displayPulseUs_;
}

void AppController::drawUi()
{
  if (!displayReady_)
  {
    // Skip all rendering if display init failed.
    return;
  }

  if (uiMode_ == UI_STATUS)
  {
    if (statusScreen_ == SCREEN_DEFAULT)
    {
      DisplayUi::drawStatusScreen(
          displayPulseUs_,
          pulseToAngle(displayPulseUs_, savedSettings_),
          savedSettings_.minPulseUs,
          savedSettings_.maxPulseUs,
          savedSettings_.reverse,
          hvMode_,
          modeLabel(),
          controlMode_ == CONTROL_SWEEP,
          sweepCycleCounter_,
          savedSettings_.burnCycles);
    }
    else if (statusScreen_ == SCREEN_GAUGE)
    {
      const uint8_t gaugePercent = pulseToPercent(displayPulseUs_, savedSettings_);
      DisplayUi::drawGaugeScreen(
          gaugePercent,
          hvMode_,
          modeLabel());
    }
    else if (statusScreen_ == SCREEN_CURRENT)
    {
      DisplayUi::drawCurrentScreen(
          inaMonitor_.ready(),
          inaMonitor_.ch1mA(),
          inaMonitor_.ch2mA(),
          inaMonitor_.ch3mA(),
          inaMonitor_.warnCh1(),
          inaMonitor_.warnCh2(),
          inaMonitor_.warnCh3(),
          inaMonitor_.critCh1(),
          inaMonitor_.critCh2(),
          inaMonitor_.critCh3(),
          hvMode_,
          modeLabel());
    }
    else if (statusScreen_ == SCREEN_VBUS)
    {
      DisplayUi::drawVoltageScreen(
          inaMonitor_.ready(),
          inaMonitor_.busCh1V(),
          inaMonitor_.busCh2V(),
          inaMonitor_.busCh3V(),
          inaMonitor_.droopCh1V(),
          inaMonitor_.droopCh2V(),
          inaMonitor_.droopCh3V(),
          inaMonitor_.warnCh1(),
          inaMonitor_.warnCh2(),
          inaMonitor_.warnCh3(),
          inaMonitor_.critCh1(),
          inaMonitor_.critCh2(),
          inaMonitor_.critCh3(),
          hvMode_,
          modeLabel());
    }
    else
    {
      DisplayUi::drawCurrentPeakScreen(
          inaMonitor_.ready(),
          inaMonitor_.peakCh1mA(),
          inaMonitor_.peakCh2mA(),
          inaMonitor_.peakCh3mA(),
          hvMode_,
          modeLabel());
    }

    return;
  }

  DisplayUi::drawSettingsScreen(
      selectedMenuItem_,
      uiMode_ == UI_MENU_EDIT,
      editSettings_.minPulseUs,
      editSettings_.maxPulseUs,
      editSettings_.reverse,
      editSettings_.sweepCycleMs,
      editSettings_.burnCycles);
}

void AppController::cycleStatusScreen()
{
  // Rotate STATUS -> GAUGE -> CURRENT -> VBUS -> PEAK -> STATUS.
  statusScreen_ = static_cast<StatusScreen>((statusScreen_ + 1) % SCREEN_COUNT);
}

void AppController::resetSweepState()
{
  // Start SWP mode from min pulse and clear cycle counter.
  sweepPulseUs_ = savedSettings_.minPulseUs;
  sweepDirection_ = 1;
  sweepCycleCounter_ = 0;
  sweepReachedMax_ = false;
  sweepBurnDone_ = false;
  lastSweepStepMs_ = millis();
}

void AppController::cycleControlMode(const int8_t direction)
{
  // Circular mode switch with UP/DOWN buttons.
  int8_t nextMode = static_cast<int8_t>(controlMode_) + direction;
  if (nextMode < 0)
  {
    nextMode = static_cast<int8_t>(CONTROL_COUNT - 1);
  }
  else if (nextMode >= static_cast<int8_t>(CONTROL_COUNT))
  {
    nextMode = 0;
  }

  const ControlMode previousMode = controlMode_;
  controlMode_ = static_cast<ControlMode>(nextMode);
  if (controlMode_ != previousMode)
  {
    // Counter is mode-local, reset when leaving/entering modes.
    sweepCycleCounter_ = 0;
    sweepReachedMax_ = false;
    sweepBurnDone_ = false;
  }

  if (controlMode_ == CONTROL_SWEEP)
  {
    resetSweepState();
  }
}
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

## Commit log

2026-02-16 Refactor app modules, add sweep counter UI, and refresh README
    [servo_power_switch.kicad_sch]
2026-02-16 Reorganize project to root layout and introduce AppController
    [servo_power_switch.kicad_sch]
2026-02-16 Add code comments, mark README as WIP, and include KiCad hardware files
    [Servo Tester.kicad_pcb, Servo Tester.kicad_sch]
2026-02-16 Add alert LED output for INA warning/critical states
2026-02-19 Update sweep settings and ignore KiCad lock/cache artifacts
    [Servo Tester.kicad_pcb, Servo Tester.kicad_sch]
2026-02-19 Normalize KiCad folder path without spaces
    [servo_tester.kicad_pcb, servo_tester.kicad_sch]
2026-02-19 Update README hardware layout and ignore legacy KiCad path
2026-02-23 Update OLED pin mapping and sync hardware files
    [servo_tester.kicad_pcb, servo_tester.kicad_sch]
2026-02-23 Switch KiCad project path back to hardware/Kicad/Servo Tester
    [Servo Tester.kicad_pcb, Servo Tester.kicad_sch, servo_tester.kicad_pcb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]
2026-04-10 Add designators, netlist, positions, and symbol library for Servo Tester project
    - Created designators.csv to define component designators for the Servo Tester.
    - Added netlist.ipc to specify the electrical connections and layout of the circuit.
    - Introduced positions.csv to provide the coordinates and rotation for each component on the PCB.
    - Established sym-lib-table to include the Servo Tester symbol library in KiCad.
    [Servo Tester.kicad_pcb, Servo Tester.kicad_sch, bom.csv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]
2026-04-10 Mark subproject as dirty in KiCad history
2026-04-10 Add 3D model of PCB for Servo Tester project
2026-04-29 feat: Add language selection and improve UI for servo tester
    - Introduced compile-time language selection for English and Czech.
    - Updated UI strings to use language-specific definitions.
    - Added support for optional power mode indicator LEDs.
    - Implemented burn cycles feature to limit servo sweep cycles.
    - Enhanced settings storage and validation for new burn cycles parameter.
    - Improved serial debug output for INA3221 communication checks.
    - Updated display functions to reflect new settings and language changes.
    - Adjusted pin configuration in documentation to match new features.
    [Servo Tester.kicad_pcb, Servo Tester.kicad_sch]
